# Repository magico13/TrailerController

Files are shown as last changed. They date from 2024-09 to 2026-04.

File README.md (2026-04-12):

# TrailerController

An open-source trailer controller emulating a Tesla trailer control module.

The goal of this project is to openly document how to create a controller that plugs into the gray 3-pin connector included on Tesla vehicles, to be able to control a 4-pin US trailer connector without needing to interface with any of the vehicle's other wiring.

The vehicle used for testing is a US-spec, Fremont factory, 2022 Tesla Model 3 LR AWD built November 2021, which puts it as SOP5. The vehicle is a HW3, MCU2 (Intel Atom), with a standard 12V lead-acid battery and ultrasonic sensors. Vehicles built starting around December 2021 shipped with a higher voltage lithium ion low-voltage battery (around 15V) and MCU3 (AMD Ryzen) with no ultrasonic sensors, and while this project should hopefully work for them the higher voltage may require some component changes.

At the time of writing, this project is intended to be passive, only reading information from the vehicle computers without attempting to send any commands to the vehicle. This is safer from both a security perspective and from the perspective of potentially damaging the vehicle electronics.

## OEM Tesla Parts

Note that since the Highland Model 3 now has an official tow package, a US-spec official ECU is available straight from Tesla that is plug and play with the older Model 3s as well. As of writing (April 2026), you can buy the ECU and the 4-pin connector from Tesla for about $100.

ECU: `1112581-00-A`
Harness: `1446560-00-A`

If you want to build your own for some reason, for example you don't want the car to disable anything when you attach a trailer, then this repository may still have value for you. If you just want your trailer lights to work with an aftermarket hitch, just buy those parts from Tesla directly.

Update: Either I got a bad wiring harness or there's something different with the communication between my older car and the newer ones that those parts are for, because my lighting appears to be out of order. Headlights control one of the turn signals, one turn signal signals the other, and the other turn signal control the tail lights. It seems like I can either swap the wires around myself, or make an adapter that plugs in and remaps them. Be warned that using those parts might result in the same issue for you!

## Working Prototype

There is a working prototype with design files available in the [prototype.md](/docs/prototype.md) doc. Code for the prototype is available in the `/src/phase1` folder.

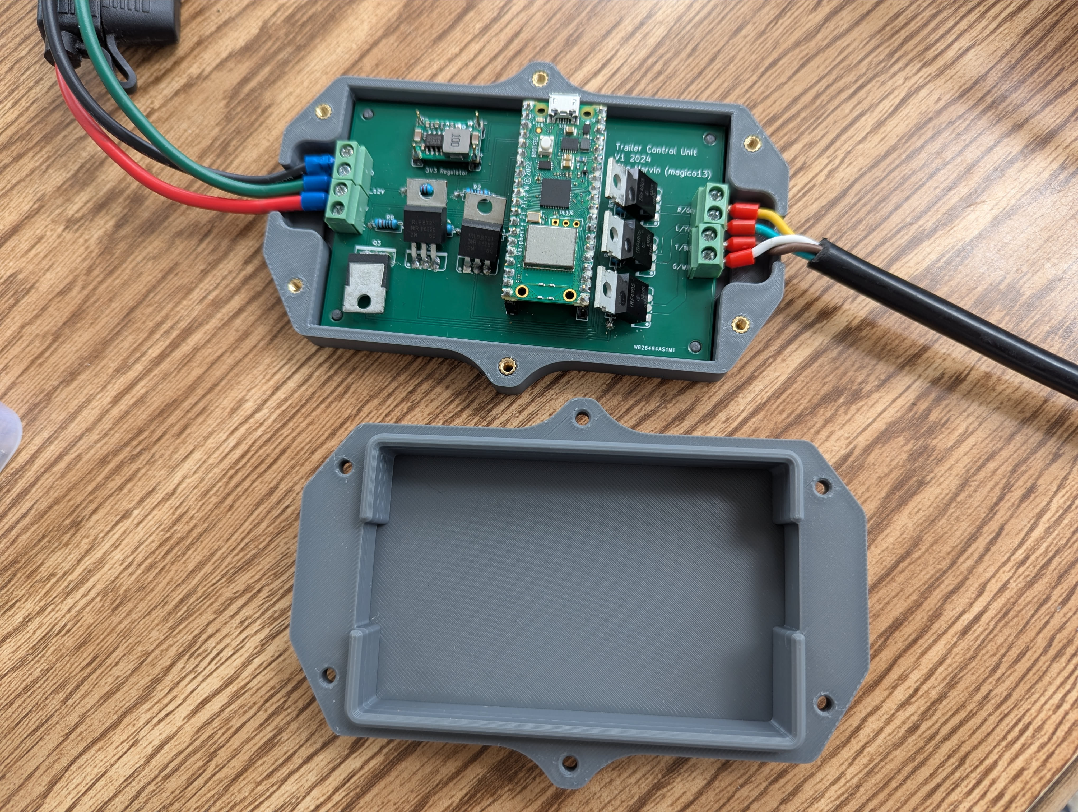
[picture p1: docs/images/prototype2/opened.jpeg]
Prototype Image


## Motivation

Currently it is difficult or impossible to find documentation of how to interface with the Tesla trailer wiring to get a standard 4-pin connector. In Europe, the "gray connector" (as it's often referred to online, see [teslamotorsclub forum](https://teslamotorsclub.com/tmc/threads/model-3-tow-hitch-installation-ecohitch-and-near-factory-wiring.323758/)) connects to the Trailer Control Unit which interprets the signals from the vehicle's computer and adapts to the standard [European 13 pin connector](https://en.wikipedia.org/wiki/ISO_standards_for_trailer_connectors#13-pin_trailer_connector_(ISO_11446)). In the US the controller is missing but the wiring up to it is present (as of 2019), terminating in the gray connector with id `X041` in the Tesla service manual.

~~I have seen reports that you can use the OEM trailer control module for a Tesla Model Y with the Model 3, to get the US 7-pin connector, part number `1764896-98-D`. Used on ebay they look to run about $300 USD but provide an OEM route for this functionality.~~ (See above, there is an official US Model 3 part for this now.) This alone does not enable the trailer mode in the software, but there are ways to do that with the Tesla Toolbox software.

There is an existing third-party module available online which goes by the part number `TM3-TDW06-US` which does precisely what this project aims to do. I cannot speak to the quality of the product, but it retails for about $400 USD and as far as I can tell the hardware and software are not open-source.

Instead of reusing this conveniently placed connector, most people opt for using "dumb" wiring harnesses that monitor the wires for the tail lights and turn signals and run a wire to a 12v source (sometimes all the way up to the battery in the front of the car) for power. Some of these wiring harnesses require electrically connecting to the wires by clamping onto and piercing the insulation of the wires, such as the "passive" wiring harness provided with the Stealth Hitch. Others monitor the wires using inductive sensors that wrap around the wire but do not pierce the insulation, but still require finding appropriate wires to intercept.

I have seen reports of people doing exactly what this project aims to do, ie listen to the communication from the vehicle over that connector and actuate the appropriate lights on the trailer, but have yet to see anyone document the process in a way that can be used by the community. Even if the wiring is relatively simple, decoding the communication is an annoying process to repeat for everyone who wants to create their own controller. I hope this project will eliminate the amount of rework required and provide a suitable starting point for anyone looking to create their own controller.

## General Plan

I expect there to be at least 3 phases of this project.

### Phase 0 - Decoding and Documenting

Documenting information about the connector on the vehicle and developing a controller that can listen to communications from the vehicle, so that we can also decode them and establish which messages indicate that the turn signals, brake lights, and headlights/taillights are active.

### Phase 1 - Functional Prototype

Taking the info from Phase 0 and building the first prototype trailer controller that will properly actuate the trailer lights via a 4-pin connector. This might be as basic as a bread-board or perf-board and not water-resistant, just a proof of concept of everything working together. This is sufficient for the purposes of this project, in that it provides all of the information required to build a custom trailer controller including functional software and hardware examples. It does not, however, get me personally to a state where I can use a trailer with my car for very long or in inclement weather.

### Phase 2 - Permanent Controller

Enhancing the prototype into something that can be installed permanently in the vehicle is a bit of a stretch goal for the project, but something that I want to personally achieve for my vehicle. This may involve custom PCBs and enclosures and additions to the hardware that are not required for a minimally viable product, eg temperature sensors and detecting if a trailer is connected. At this point I may also investigate sending data back to the vehicle to let it know if a trailer is connected, so that trailer mode could be engaged if enabled in the software (the controller cannot enable tow mode itself, the main software must be updated through Toolbox to allow it). While all the hardware and software produced at this stage will remain open-source, I may opt to sell completed or kit versions of the final result if there is interest.

## Docs

Check the docs folder for the most up-to-date information about the connector, communication, and the latest project status. These documents will be living documents during the research and development of this project.

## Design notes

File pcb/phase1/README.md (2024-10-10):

# phase1

## Description

Schematic and PCB for phase 1. PCB is definitely optional, but may provide a starting point. At the very least, it's good learning for me to make.

This is a [LibrePCB](https://librepcb.org) project. LibrePCB is free, open-source, and cross-platform.

## License

See [LICENSE file](../../LICENSE)

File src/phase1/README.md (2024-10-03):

# Phase 1

This second phase is for building a prototype controller. While an ESP32 was used for the first Phase 0, a Pi Pico W is being used here. Some of the fancier OTA support is lost as a result.

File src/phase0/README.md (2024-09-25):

# Phase 0

This first phase is just to get a device connected to the LIN network and listening to the communication so we can find the messages we need to trigger off of. This folder specifically contains the source code for the ESP32 doing the listening.

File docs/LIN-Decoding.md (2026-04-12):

# LIN Decoding

The communications from the vehicle to the trailer control unit are performed over the thinner middle wire in the connector (see [X041.md](./X041.md)) which communicate via a [Local Interconnect Network](https://en.wikipedia.org/wiki/Local_Interconnect_Network), ie LIN. Notably, LIN is not CAN (Controller Area Network), but instead is a cheaper and simpler serial communication protocol that is bidirectional via a single communication wire.

During Phase 0 of the project this page will (hopefully) document the communication happening via the LIN wire and identify the message(s) that provide the information we need to run the trailer lights.

## Target information

This is the information that we definitely will need to read from the LIN to activate the correct lights.

- Brake light status
- Left/Right turn signal status
  - Will the messages indicate the current state of the light within the cycle (on/off) or instead just that left/right is requested?
  - Are hazard lights communicated differently?
- Taillight/Headlight status
  - Specifically the taillights are what is required, but that may only be communicated by if the headlights are active
  - If headlights only, regular vs brights may be communicated differently?

## Hardware Setup

To connect to the vehicle and read the data I am planning on using an ESP32 with one of the serial RX pins connected to the LIN wire. Since the LIN uses 12V and the ESP32 is 3V3 and we only need to read data, a simple voltage divider to cut the voltage to about 1/5 of normal should suffice to prevent the ESP32 from being overvolted. I plan on powering the ESP32 directly from the 12V wire via the VIN pin and use the onboard regulator, but in the future a separate (probably switching) regulator to drop to 3V3 that can definitely handle up to about 20V should be used instead.

I am opting for an ESP32 because WiFi capability means I can update the firmware and get data without having to run a wire to the controller from my computer (meaning I can hopefully sit in the drivers seat and read data as I activate things) and because there are [existing LIN libraries](https://github.com/iDoka/awesome-linbus) for the ESP32. I may instead swap to a Raspberry Pi Pico W in the future, or to a custom RP2040/RP2350 board. Using a standard and relatively inexpensive development board means that everything is easily replicated by anyone else wanting to create a custom controller using this information.

The source code provided in this project is set up to use PlatformIO via Visual Studio Code, which should make it relatively simple to update and flash on your own hardware.

The circuit diagram for the reader is below, basically just a voltage divider using 47kOhm and 10kOhm resistors to drop the voltage to below 3.3V and into a safe range for the RX2 pin on the ESP32. I ended up logging to serial rather than building out a web server, so power was generally provided by USB rather than the 12V.

Circuit diagram

Alternatively, use a dedicated USB signal analyzer, which is what I ended up doing later, using the PulseView software for Linux. For reference, 100kHz sampling rate seemed to work fine, which is about 5x the data rate.

## LIN Information

There are some basic settings for the LIN bus that seems to be common between at least the LIN bus for the trailer and the inductive charger:

- LIN checksum version: 2
- Baudrate: 19,200 bits/s
- Data length: variable

Example trace from the inductive charger LIN bus:
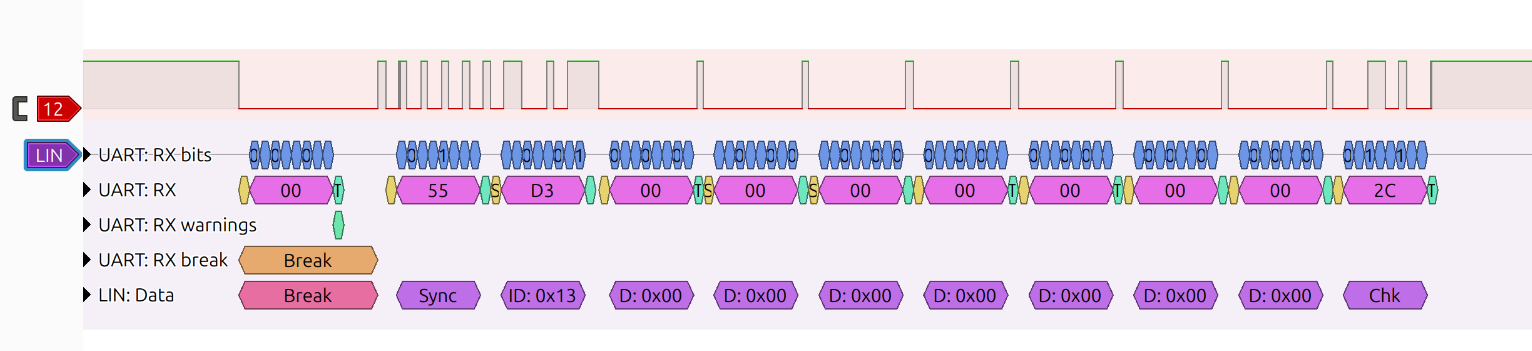
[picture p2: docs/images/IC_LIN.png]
IC_LIN example


~~Further testing indicates that the same data looks to be sent over both LIN buses. The light info for the trailer can be read over the LIN for the inductive charger, which makes debugging much easier since that can be read from within the cabin.~~

While the above is true, newer documentation for the Highland Model 3 shows that LIN bus 2 from the left body controller contains both the trailer LIN and the inductive charger LIN on the same bus. There are additional LIN buses in the vehicle, but those two will always both be available together, which is extremely convenient because that means we can access both from either the rear bumper, or from the center console.

## Testing Setup

Within the center console, the connector numbered `X930` within the Tesla documentation is the one we'll be interfacing with for reading data and testing purposes. One option for probing here is to insert male jumper cables for breadboards into the backs of the connector, which is what I did for a long time. However, there are a plethora of aftermarket OBD2 adapter harnesses you can buy that are installed in-line with this connector, which you can modify without worrying about damaging the original wires or having to build a whole pass-through harness for the three wires we care about. I ultimately ended up modifying the one I already had installed for Scan My Tesla and added the same female connector that exists in the rear bumper for the trailer ECU.

On my vehicle, pin 1 on this connector is 12V, pin 6 is the LIN bus, and pin 26 is ground. Double check via Tesla's documentation for your specific build, and also with a multimeter! Searching for `X930` in the interactive schematics on Tesla's service website should be enough to pull up the pinout.

The picture below shows the testing setup with a full prototype unit, but the same basic idea works for testing with just a signal analyzer.

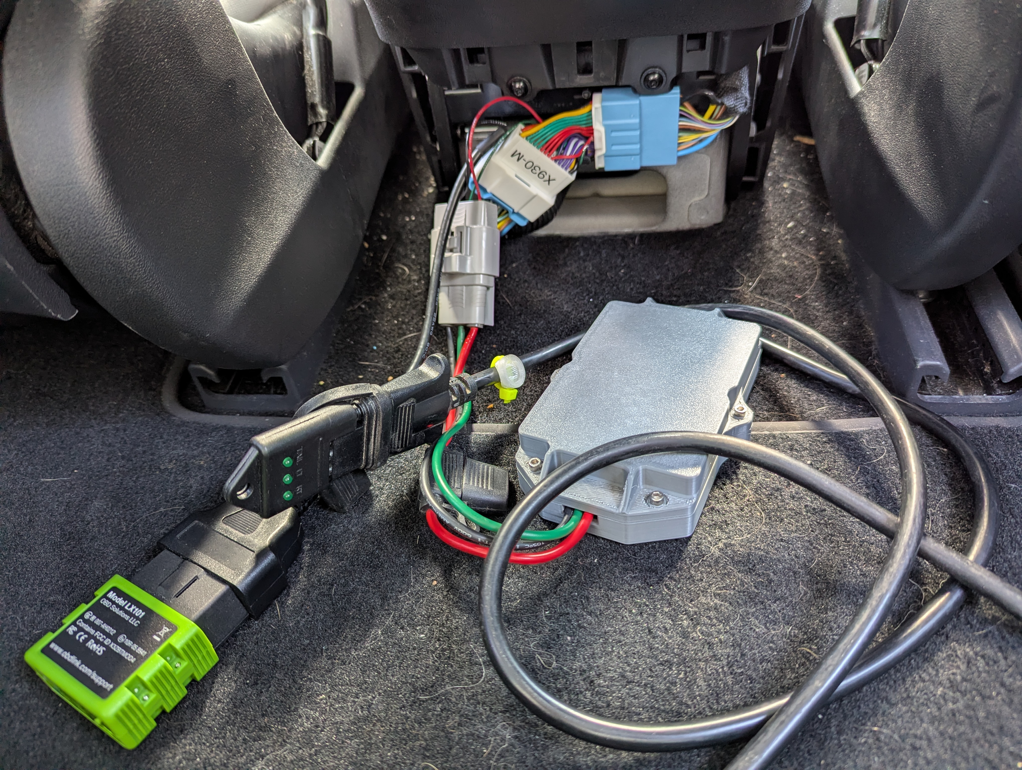
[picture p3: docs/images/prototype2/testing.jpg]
Setup


### Reading the Lights Data

As you can tell if you look at the raw data below, the key message for the data on which lights are lit is the message with ID `0x0F`. This message has a single byte of data containing flags for the relevant lights.

In least significant bit first ordering (how the data is sent over UART):

- Bit 1: Left turn signal
- Bit 2: Right turn signal
- Bit 3: Headlights
- Bit 4: Brakes
- Bit 5: Unknown
- Bit 6: Reverse lights
- Bits 7-8: Unknown

Both of the turn signals are also marked as active when the brakes are pressed, so that doesn't need to be handled separately.

This means that mapping the message to the lights on a four-pin connector is just:

- left/yellow maps to the first bit
- right/green maps to the second bit
- taillights/brown maps to the third bit

#### Examples

- Driving with the headlights on: `00100000` = 0x08
- Headlights on, turning left: `10100000` = 0x09
- Slowing down with brakes, headlights off: `11010000` = 0x0A

### LIN Frames

This is a raw list of the different ids and sample data seen for the Trailer LIN bus. Number are hex unless otherwise specified. ID is the actual identifier, PID is the raw Protected Identifier Field including parity bits.

#### 0x0F - Light States

- ID: 0x0F
- PID: 0xCF

IDLE

- Data: 1 byte
  - 0x00
- Checksum: 0x30

LEFT TURN

- 0x01
- Checksum: 0x2F

RIGHT TURN

- 0x02
- Checksum: 0x2E

LIGHTS ON

- 0x04
- Checksum: 0x2C

BRAKES

- 0x0B
- Checksum: 0x25

DRIVE - HOLD ACTIVE

- 0x0F
- Checksum: 0x21

REVERSE - HOLD

- 0x2F

REVERSE - MOVING

- 0x24

#### 0x10 - Data from ECU to Car

- ID: 0x10
- PID: 0x50
- Without ECU: No data, expecting response
- With ECU:
  - Park, no connection: 5 bytes
    - 0x00
    - 0x00
    - 0x2C = `00101100`
    - 0x01
    - 0x00
    - Checksum: 0x82
  - Park, connected: 5 bytes
    - 0x49 = `10010010` determined to be left test/status/unknown, right test/status/unknown, tail test/status.
    - 0x00
    - 0x2C = `00101100`
    - 0x01
    - 0x00
    - Checksum: 0x39
  - Park, only tail lights (car thinks left turn):
    - 0x81 = `10000001`
    - others unchanged
  - Park, only LT (car thinks right turn):
    - 0x08 = `0010000`
    - 0x00
    - 0x30 = `00001100` <- different!
    - 0x01
    - 0x00
    - Weirdly, the car indicates the left is out and the right is fine (fast left blinks, normal rights)
  - Park, only RT (car thinks tail lights):
    - 0x40 = `00000010`
    - 0x00
    - 0x30 = `00001100`
    - 0x01
    - 0x00
    - Car indicates both left and right are in error.

  Uh oh, testing with my light tester shows that either the harness is wired wrong or there's a bug in the ECU code because the RT light is tied to the headlights, LT light is tied to RT, and Tail lights is tied to LT. That's a huge issue for using the existing ECU, I will need to investigate further.

  - Reverse, fully connected, brakes active
    - 0x5B = `11011010` - left good, left active, right good, right active, tail good, tail off
    - 0x04 = `00100000`
    - 0x51 = `10001010` - first bit seems to be "reverse" but otherwise I don't see a consistent pattern
    - 0x01 = `10000000`
    - 0x00

  - Drive, connected, free rolling:
    - 0x49 = `10010010`
    - 0x00
    - 0x50 = `00001010`
    - 0x01
    - 0x00

  - Drive, connected, headlights on, free rolling:
    - 0xC9 = `10010011` - left/right good, tail good, tail active
    - 0x00
    - 0x50 = `00001010`
    - 0x01
    - 0x00
  
  - Drive, connected, brakes on:
    - 0x5B = `11011010`
    - 0x04 = `00100000` definitely seems brakes related
    - 0x50 = `00001010`
    - 0x01
    - 0x00

#### 0x11 - Unsure, comes from trailer ECU

- ID: 0x11
- PID: 0x11
- Without ECU: No data, expecting response
- With ECU:
  - Park, connected or not: 8 bytes
    - 0x01
    - 0x00
    - 0x00
    - 0x00
    - 0x00
    - 0x00
    - 0x00
    - 0x00
    - Checksum: 0xED
  - Drive, brakes active, right turn signal
    - 0x86 = `01100001`
    - 0x03 = `11000000`
    - rest 0x00
  - Drive, headlights on, rolling
    - 0x02 = `01000000`
    - 0x01 = `10000000`
    - rest 0x00
  - Drive, brakes (and also Reverse, brakes)
    - 0x86 = `01100001`
    - 0x85 = `10100001`
    - rest 0x00

#### 0x13

- ID: 0x13
- PID: 0xD3
- Data: 7 bytes
  - 0x00 (for all bytes)
- Checksum: 0x2C

#### 0x18

- ID: 0x18
- PID: 0xD8
- No data, expecting response

#### 0x19

- ID: 0x19
- PID: 0x99
- No data, expecting response

#### 0x29 - Driver Side Wireless Charger

- ID: 0x29
- PID: 0xE9
- Data: 8 bytes
  - 0x02
  - 0x00
  - 0x1C
  - 0xF3
  - 0x01
  - 0x88
  - 0xFF
  - 0xFF
- Checksum: 0x7A

Driver IC Charging

- The first byte changes from 2 to 3, to 8, 9, and then 0x0A when a device is placed on the driver's side charger, but not the passenger side.

0x01 is disabled?,
0x02 is idle,
0x03 is testing for a device,
0x08 and 0x09 seem to be preparing,
0x0A is actively charging.

The second byte seems to also be a state identifier: 0 for no device, 1 for present but not charging, 2 for charging.

#### 0x2A - Passenger Side Wireless Charger

- ID: 0x2A
- PID: 0x6A
- Data: 8 bytes
  - 0x02
  - 0x00
  - 0x00
  - 0x1C
  - 0xF3
  - 0x01
  - 0x88
  - 0xFE
- Checksum: 0xFA

#### 0x2C

Note: I only saw this for the first time after installing the ECU, but a lot of time passed between the first data I captured and then, so I do not know when this was added.

- ID: 0x2C
- PID: 0xEC
- Data: 8 bytes
  - 0x03
  - 0x00
  - 0x00
  - 0x00
  - 0x00
  - 0x00
  - 0x00
  - 0x00
- Checksum: 0x10

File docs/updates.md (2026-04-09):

# Updates

## 2024-09-25

First attempt at using some fairly simple code to sniff the traffic on the LIN bus for the inductive phone charger did not really go well. May have been as simple as a timing problem, may have been that the code I found wasn't built to handle a real LIN bus and was intended for a bus of your own devices. I have ordered an inexpensive USB logic analyzer and am hoping looking at the raw signals will help me understand how to either modify the code I am using or write a whole new library if necessary.

I have also ordered a TJA1020 transceiver module. I am hoping not to need it for just sniffing the traffic but it might make development easier and will basically be required if we ever want to send data back to the controller and pretend to be the real trailer module.

You may have noticed up there that I mentioned the inductive phone charger LIN and not the trailer LIN. The connector for the trailer LIN, [X041](./X041.md), is pretty firmly trapped in the bumper in a way that prevents any access until you take the bumper off. I will reposition it when I install my hitch since I'll be in there anyway and I'm likely going to need to connect to it often during testing. Until then, for the purposes of testing whether or not I can even read data from one of the LIN buses, the bus for the inductive phone charger is much easier to access.

For reference, it's on PIN 6 of connector X930F in my model 3. That connector is the one in the bottom rear of the center console, the same one that OBD adapters are usually made to connect to. Pin 7 is conveniently a ground pin. You can disconnect that plug, stick two male jumper wires in, and have access to the LIN bus while sitting comfortably in the back seat of the car. If/when I also need 12V it can also be pulled off that connector, for example pin 15 (big one in the bottom left) looks to be the 12V for the USB ports.

I will likely continue to use that LIN bus for testing until I can reliably read data from the bus, then move to the trailer bus.

## 2024-09-26

While I wait for the USB logic analyzer to arrive I realized that I could probably use the ESP32 itself as a logic analyzer. Using [this project](https://github.com/EUA/ESP32_LogicAnalyzer) with a tweak to the `platformio.ini` file to use `espressif32@4.1` to fix the compatibility with `esp32doit-devkit-v1`, I was able to successfully read the data from the inductive charger LIN bus, though with the sensors disconnected so there was no response data (ideally I will be able to intercept it while active). That was enough to confirm some details of that LIN bus that will hopefully translate over. I'll update the [LIN bus doc](./LIN-Decoding.md) with some of that info. Additionally the sigrok/PulseView file itself is in the phase0 docs folder, [here](/src/phase0/data/IC_LIN_Trace).

Assuming the setup is the same for the trailer LIN, we at least know the protocol version (2), baud rate (19200), and to expect the amount of data per response to change between 2, 4, and 8 bytes. I think that might be why the code I was using earlier failed since I believe it was assuming the response was always 8 bytes. If I can change that to pick the right number of response bytes, maybe it'll work.

## 2024-09-29

Installed my hitch yesterday and freed the connector for the trailer wiring so that I can easily connect/disconnect from it. Ideally anyone following this will not need to move it and can leave it in the relative safety of the upper part of the bumper on the support beam, but I need to be able to freely and temporarily connect things to it.

With that available I was able to get readings from the LIN bus with the turn signals, brakes, and lights on. Now I just have to analyze the different frames and see what's different in each scenario.

## 2024-10-02

For Phase 1, the prototype controller, I am swapping to a Pi Pico W from the ESP32. I want to experiment with different hardware a bit and there are aspects of the Pico and its production that I prefer. Sadly the nice OTA library I was using doesn't play as nice, though might be able to come back without the async functionality. Also realized the other day that the MOSFETs that I got are better for low-side switching and we need high-side switching, so I got some others I need to do testing with. Annoyingly it looks like I need to use both types to be able to switch it. I have some experience with building circuits and PCBs and such, but not quite the level that would make this project easy for me.

## 2024-10-06

Prototype PCB design is finished enough to send off to get the first samples. Fingers crossed I didn't mess anything up too badly, I'll know in about a week if the estimates are to be trusted. With only 1 oz copper the lighting traces might only be good for about 3 amps, I'll have to test one of the boards at high current and see how it behaves. Ideally for a final product I'd double the copper but that increased the cost significantly, not worth it for a prototype where I know I'm only going to drive LEDs and I don't know if the board is even gonna work. Here's hoping I'll have some assembly and testing news in my next update.

## 2024-11-04

Prototype boards arrived and I've built one up. Works more or less perfectly! I did tweak the silk screen a bit since then to hopefully make the labels for the terminals more clear when the terminal blocks are attached, right now they are mostly covered. Designed and printed a pretty basic enclosure but it's both too big and too small. The horizontal space inside is a little tight, you may want to make it a bit wider to give more room for the wires coming into the terminal blocks. But it's also pretty tall, which could be improved if you bent the MOSFETs instead of leaving them straight like I did. You could go even thinner if you directly mounted the Pico. As it stands I've got it tucked into the space between the back of the bumper and the battery, my cable from the car is pulled all the way down so I can easily plug it in or take it out. I do not know if the case as designed will fit inside the bumper on top of the aluminum support where the connector from the car is normally located. I'll post pics and some more info in [prototype.md](/docs/prototype.md)

## 2026-04-05

Between the last update and now I had kept the prototype in my car for several months, over the winter even, and had used it to tow a Home Depot 5'x8' trailer once without issue. I took it out to see how it was doing, especially because I hadn't sealed the holes in the enclosure and where it sat on the underbody tray would often end up with puddles of water. Several of the exterior screws I used had rusted but the PCB itself looked fine, however once screw got stuck to the brass insert and I ended up ripping it out of the enclosure so I needed to print a new one. I figured since I needed to print a new enclosure anyway, it'd be a good time to redesign it to be smaller in the hope of fitting it higher up in the bumper and away from standing water. I'll put a few pictures of the new design up.

I've periodically been making small updates to the firmware. I'm trying to rewrite the LIN decoder because although it works perfectly fine for the short message used for the lights control, it struggles with longer messages and keeping up with the full unfiltered message list. I'd like to add a built-in data logger for monitoring the LIN bus in case anything changes or I want to try to monitor any of the other messages on the bus, although this particular one should only be the trailer hitch ECU and the wireless charger ECU.

Also since then, the Highland Model 3 in the US has gotten an official tow hitch, and the Highland appears to use the exact same wiring setup, meaning the ECU for that model should work just fine in earlier model years. You can find that ECU on the Tesla parts catalog under `1112581-00-A` and per their website it's only $60, though on eBay it's over $100. I have ordered one to try it out, if that works without issue then it would definitely be the recommended way to handle the trailer lights even with an aftermarket hitch. If you go this way, make sure to also order `1446560-00-A` which is the wiring from the ECU to the 4-pin connector, which is an additional $30.

And finally, I will provide some documentation around the LIN bus that you can access in the center console. I noticed I hadn't documented that thoroughly, including writing down the connector number (it's `X930`) anywhere for looking up the pinout, which caused me a lot of wasted time trying to find that again when I wanted to set up a more permanent test setup in my car with the same connector as what's in the bumper area.

## 2026-04-08

Good news! The parts listed above from Tesla seem to work perfectly! Even without the towing software installed (which is technically already installed but not enabled, you supposedly can enable it with Toolbox but that's like $75 minimum just to rent the software for a day), when plugging in a trailer (or just a tester in this case) the car will display a yellow trailer icon on the screen. It will also show red if one of the lights doesn't appear to be working, though doesn't seem to tell you which of them is faulty. Based on the lights on my tester, the ECU just sends a pulse every second to see if the lights are working and a trailer is attached. I am not sure if that only happens in park or even in drive and I haven't had a chance to sniff the LIN bus to see what data the ECU is sending back to the main controller.

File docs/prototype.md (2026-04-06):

# Prototype 1

This is the result of Phase 1, a fully functional but fairly basic initial prototype. This can be used as-is, though if you're going to make it I recommend some tweaks that you can look into implementing yourself.

## Final Result First

Here's the final result first, if you want to read more about the PCB and the components you can keep scrolling down.

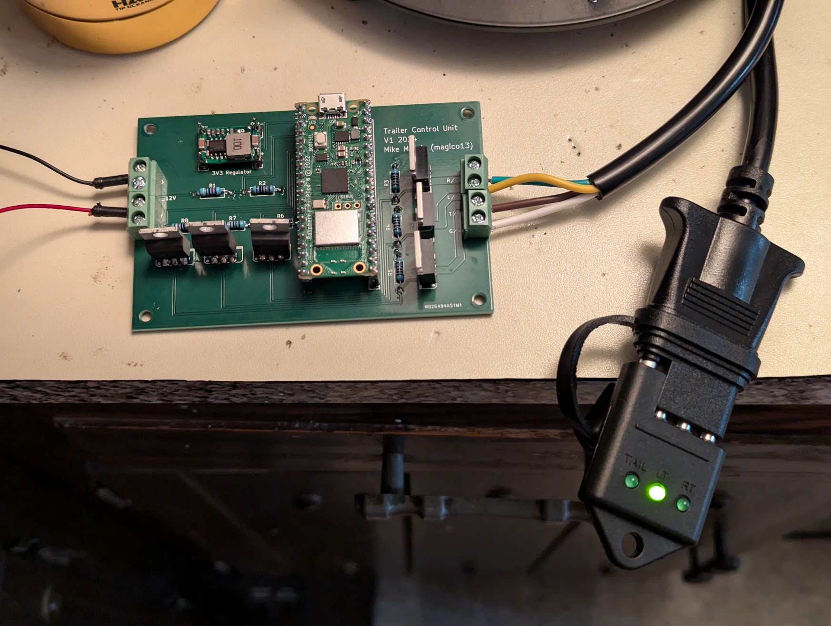
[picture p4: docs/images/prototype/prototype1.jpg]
Prototype Picture

EnclosureOpen
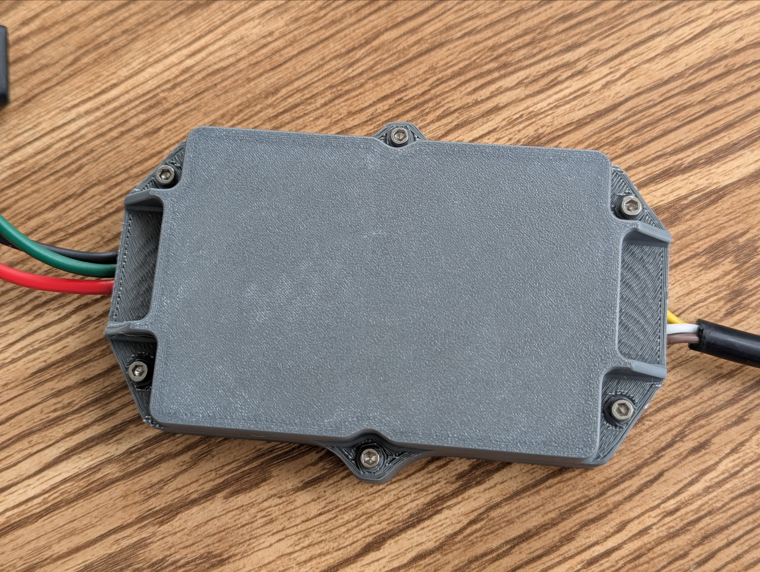
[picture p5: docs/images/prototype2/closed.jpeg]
EnclosureClosed

TestInstall

(the wiring is wrong in the picture of the open enclosure, the yellow and green are swapped, I fixed that later)

## PCB Design

The PCB was designed with LibrePCB, which is free and cross-platform. The files for it can be found in the pcb/phase1 folder and LibrePCB will interface directly with PCBWay (who I used) and other fabs to get boards uploaded and manufactured without having to do any exporting of files or much in the way of configuration. I did opt to put `WayWayWay` at the bottom of the board to force the PCBWay serial into that location, make sure to check that option if you use PCBWay or remove that text if you don't care.

I am not very experienced with PCB design so there are definitely improvements that can be made. I wanted to provide what I created and used as a stepping stone for anyone else who might want to do something similar. If you are more experienced or think you can make something better, please do and share it!

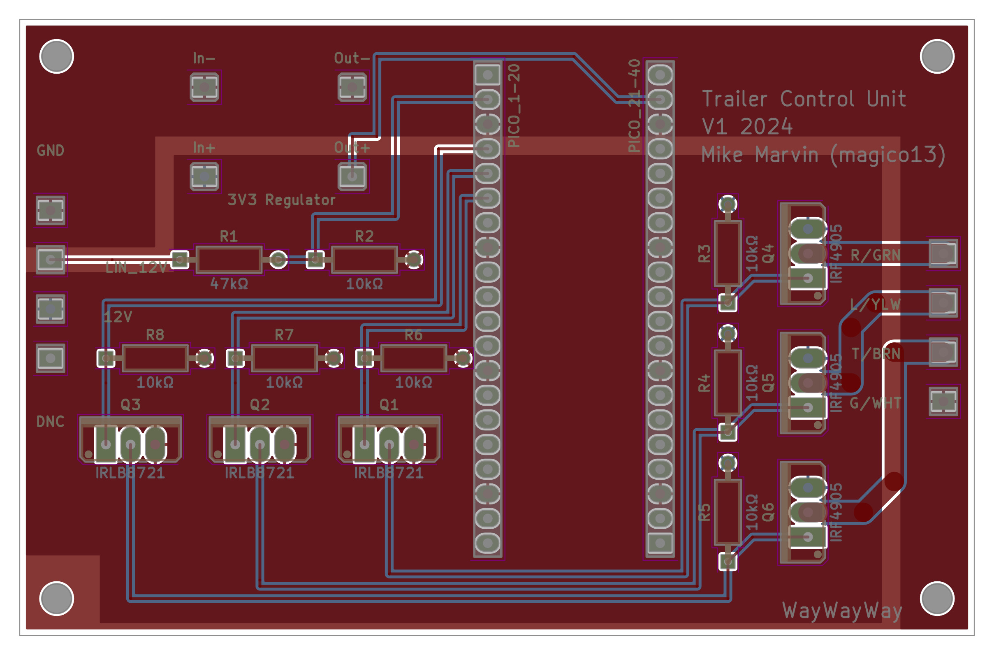
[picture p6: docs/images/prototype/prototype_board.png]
Prototype Board

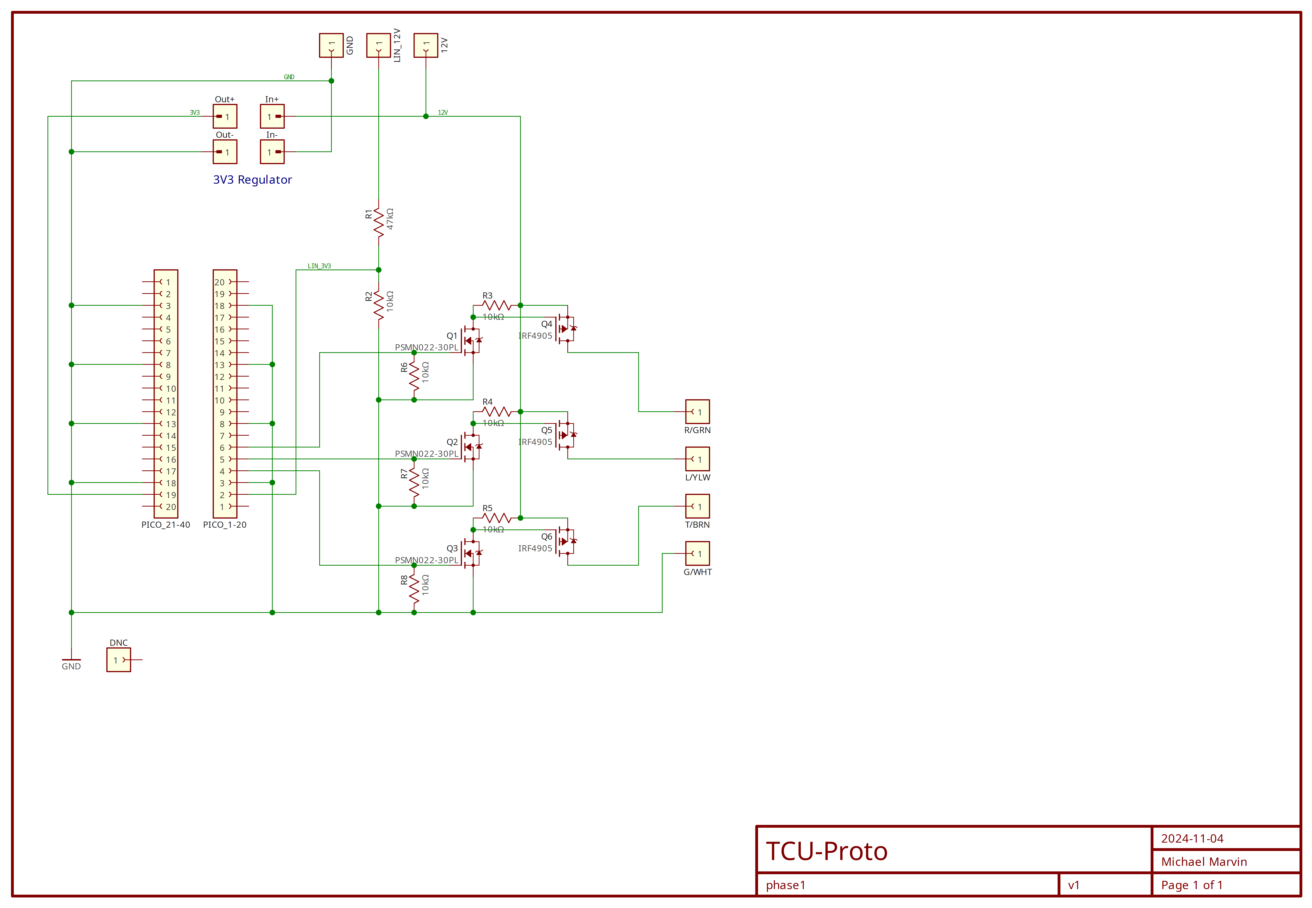
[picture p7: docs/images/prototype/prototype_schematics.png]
Prototype Schematics


## New Enclosure

See below for details about the old, larger enclosure, which is still available via OnShape. For the updated enclosure, the MOSFETS must be bent so they don't stick up past the Raspberry Pi Pico, but it shaves off a fairly good amount of height and is about the same width with the wings, it'd be noticeably smaller if you removed them from the model but I'm not sure if the outer four screws are enough or not. This update was also made in OnShape at the same link. This new enclosure doesn't use screws to hold down the PCB, instead the inner walls of the top of the enclosure hold it down and there are pins that the mounting holes on the PCB sit on, so that removes four screws and brass fittings. The design does unfortunately require support and was designed around a 0.4mm nozzle, if I make more updates to it I will try to reduce the support requirements, but in this case I had to decide between really long screws or using support.

The new enclosure is designed so that the PCB can be removed without removing the wires from the terminal blocks, and so that the pico's USB port is accessible even while the PCB sits in the bottom of the enclosure. The intent is to fill the wire openings with hot glue or epoxy or something similar to seal them, though I am also considering making a printable TPU gasket.

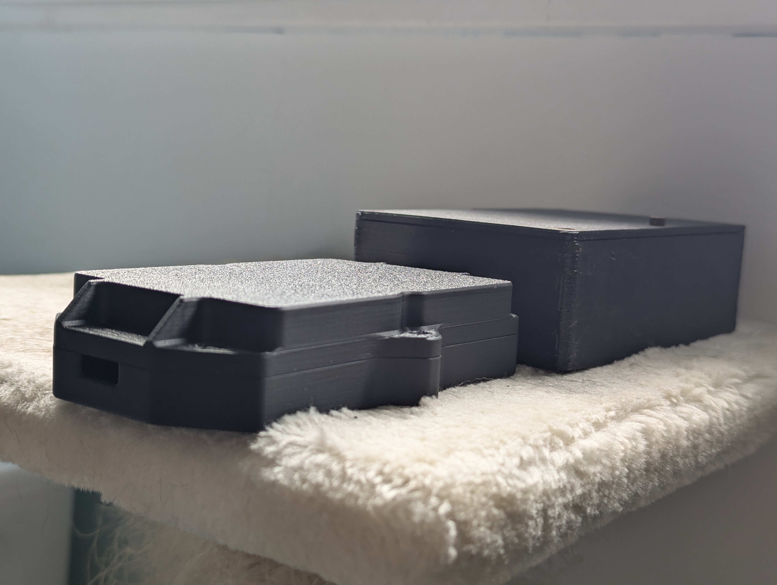
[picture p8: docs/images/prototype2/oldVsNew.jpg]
OldVsNew


The new one is black here because it was a test print in PLA, the final version was printed in a gray PETG.

## Old Enclosure

The enclosure was designed in OnShape. I tried to learn FreeCAD and it was too frustrating for me coming from Fusion 360, but I wanted something that worked on Linux. With OnShape being browser based it worked fine in Ubuntu or on my Windows desktop. With the public link you should be able to copy it to your own account to modify, or export it in whatever format you want. Again, I'm experienced enough to make something **functional** but not necessarily something **good**. I am not sure how this will hold up over time, or how water resistant it is. I printed it with a 0.6mm nozzle at 0.4mm layer height, but it was designed to also support 0.4mm nozzles for the walls. There's a rough model of the PCB with the terminal blocks, Pico, and MOSFETs included to help with positioning.

<https://cad.onshape.com/documents/38c75cc318c0ba98099f4117/w/3ef348a47c70d4d10d24442a/e/2bfd670c77f872a4c310e10b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>

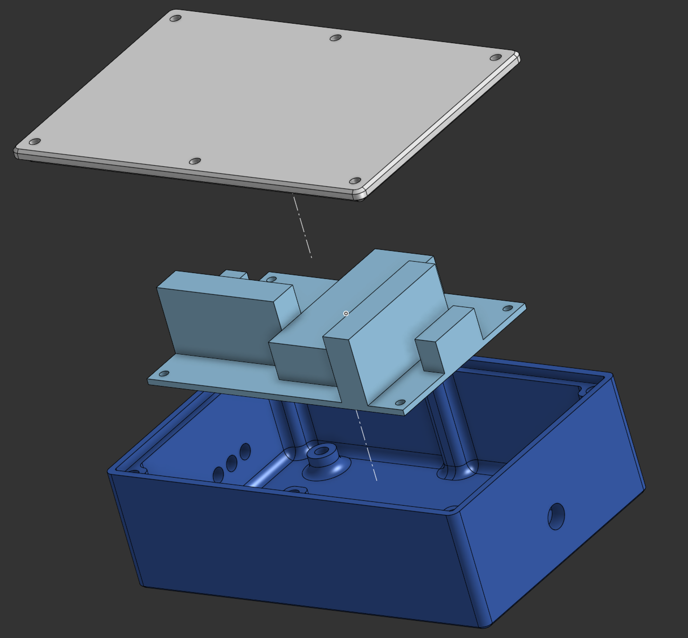
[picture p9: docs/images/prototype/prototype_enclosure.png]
Enclosure


## Bill of Materials

If you want to build your own copy of one of these boards, here are the materials I used.

### Main PCB

| Name | Quantity | Link | Notes |
| --- | --- | --- | --- |
| Pi Pico W | 1 | [Raspberry Pi Official Site](https://www.raspberrypi.com/products/raspberry-pi-pico/?variant=raspberry-pi-pico-w) | You can use the non-wifi Pico if you want more security, but lose out on easy updates and control. |
| 1x20 female pin headers | 2 | generic | For the Pi Pico. You could optionally solder it directly. I had a 1x40 already that I cut in half. |
| IRLB8721 N-Channel MOSFET TO-220 package | 3 | <https://www.amazon.com/dp/B07LG5BCDY> | These are overkill for this application, you really just need something that operates at 3V3 gate voltage. They will not carry any real current. |
| IRF4905 P-Channel MOSFET TO-220 package  | 3 | <https://www.amazon.com/dp/B0CBKH44K5> | There are probably better choices but I had bought the N-Channels first before I realized you can't high-side switch with them and these are what I could get quickly. |
| 3V3 Regulator | 1 | <https://www.amazon.com/dp/B0B779CGJQ> | You could use a linear regulator instead for simplicity but that adds more heat. These have crappy spacing, 0.3625"x0.6". I used single male pin headers to affix them to the main board. If you plan to plug in USB to the pico while it's onboard, I recommend adding a diode because this doesn't like being run backwards. |
| 47kΩ resistor | 1 | generic | Only non-10kΩ resistor, used to drop the LIN Bus voltage to something the Pico can work with. This is R1 on the board. |
| 10kΩ resistor | 7 | generic | Used in the voltage divider for the LIN Bus and as pull-down/pull-up resistors on the MOSFETs. |
| 4x5mm/0.2" terminal blocks | 2 | generic, maybe <https://www.amazon.com/dp/B0D1GMMTZ5> | I already owned ones that were 2x so I used two next to each other. You can use a 3x on the car side, the fourth hole doesn't do anything but provide the option of using a 4x or two 2x terminals. |

### Enclosure/Other

| Name | Quantity | Link | Notes |
| --- | --- | --- | --- |
| M3 Heat-Set Inserts | 6 | <https://www.amazon.com/dp/B0CS6VZYL8> | 6 for the lid |
| M3x10mm bolts | 6 | generic | Longer will also work |
| Trailer Wire Harness | 1 | <https://www.amazon.com/dp/B0CM3Q5XL8> | The hole in the side is designed to fit the shielding of this pretty tightly. Others may work just as well. |
| Trailer Wire Tester | 1 | <https://www.amazon.com/dp/B07RT9CN3W> | Purely optional, nice for bench testing or if you don't have a trailer to test with. |
| Sumitomo 6188-0129 connector (with wire seals and blades) | 1 | <https://www.corsa-technic.com/item.php?item_id=1846> | See [X041.md](/docs/X041.md) for more details. |
| 12 gauge wire | 3 | generic | I had 12 gauge on-hand in red/black/green so that's what I used and what the holes are sized for. |
| Wire ferrules | 3 or 7 | <https://www.amazon.com/gp/product/B07WRQN45C> | These are generally recommended when you're using terminal blocks and stranded wire, but not strictly required. |
| 10-amp In-line Automotive Fuse | 1 | <https://www.amazon.com/gp/product/B01E5MM63C> | I've had this set for a while. A fuse is not strictly required but highly recommended. Might be tricky to replace if you tuck the TCU on top of the aluminum support. |

## Potential Improvements

In no particular order:

- Add a diode between the output of the 3V3 regulator and Pico to prevent backfeed when USB plugged in.
- Add smoothing capacitors across power lines.
- Shorten the height of the enclosure (further) by bending the MOSFETs (or SMD components).
- Better MOSFET choice(s).
- Resettable fuse if device placed out of reach (ie on the support beam).
- Automatically detect trailer connection instead of having to enable via web page.
- New PCB with surface mount components and much smaller size (ie Phase 2).
  - Potentially fully custom RP2040 setup, but would increase the complexity significantly.
- Different regulator. Either a basic linear one or otherwise put the power components on the PCB.
- Use TJA1020 or similar to send data back to the car.

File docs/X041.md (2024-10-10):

# X041 - The Gray Connector

X041 is the identifier of the "gray connector" for the trailer wiring harness in the Tesla service manual. The part is Tesla Part Number `1450449-00-A` and connector part number `Sumitomo 6189-0165`. The mating part that you would need to source to seamlessly connect to the connector in the vehicle is `Sumitomo 6188-0129` which can be found online via a variety of retailers, including AliExpress. I personally purchased mine from [CorsaTechnic](https://www.corsa-technic.com/item.php?item_id=1846) for about $5 plus $5 shipping, since shipping was from the US. I chose pins and seals fitting 3.00 mm<sup>2</sup> wire, as that is what is used for the power/ground wires on the Tesla connector.

The Tesla side of the connector has three wires, on the outside are red 12V and black ground in 12 gauge (TODO: confirm size) wire with the middle 18(?) gauge green wire being a Local Interconnect Network interface (see [LIN Decoding](./LIN-Decoding.md)) used for communicating vehicle status.

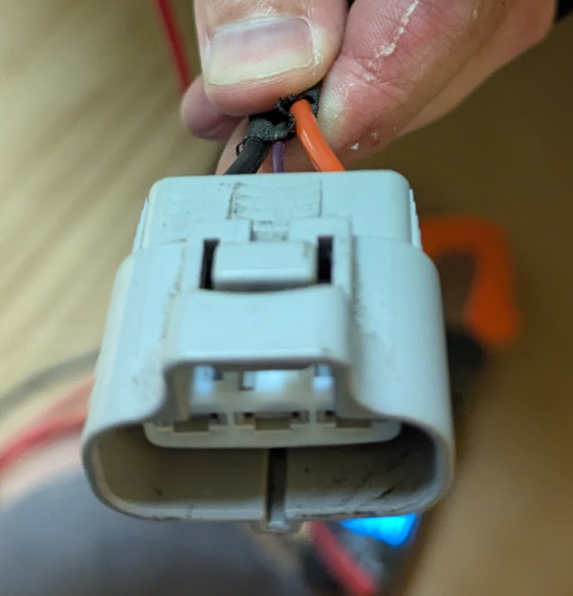
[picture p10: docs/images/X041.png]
X041 connector


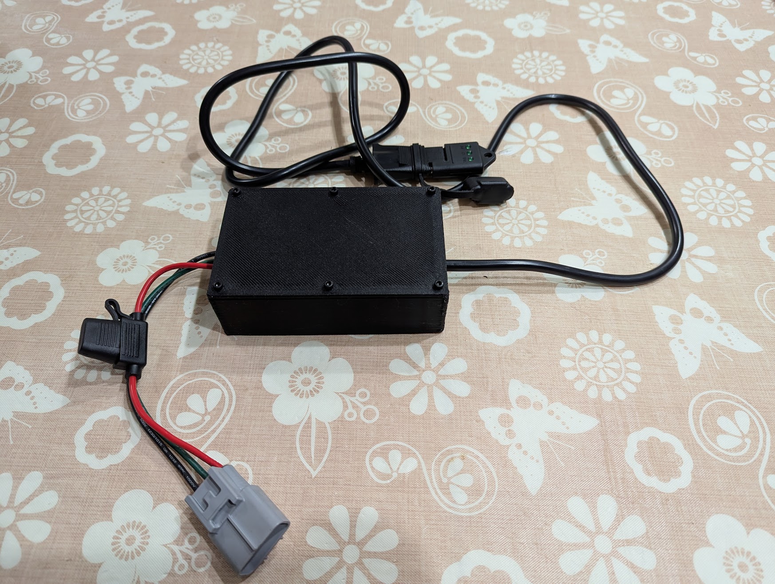
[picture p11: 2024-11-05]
docs/images/prototype/prototype4.jpg

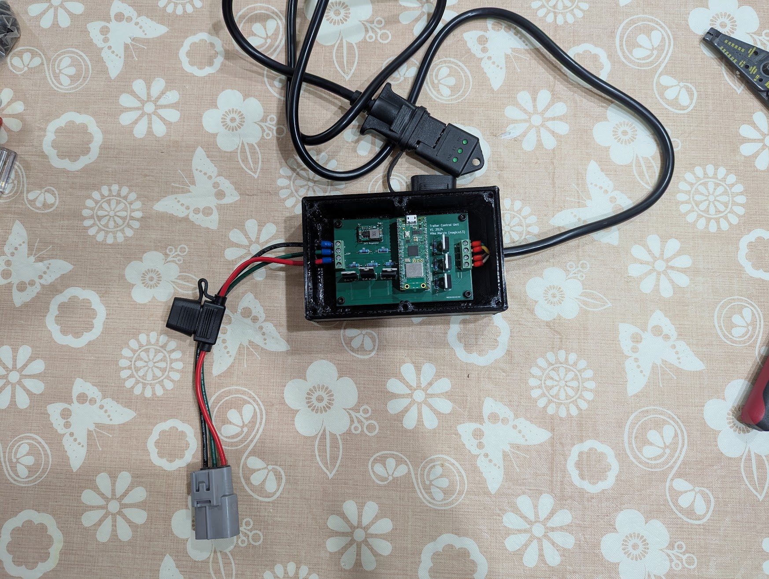
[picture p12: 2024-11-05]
docs/images/prototype/prototype2.jpg

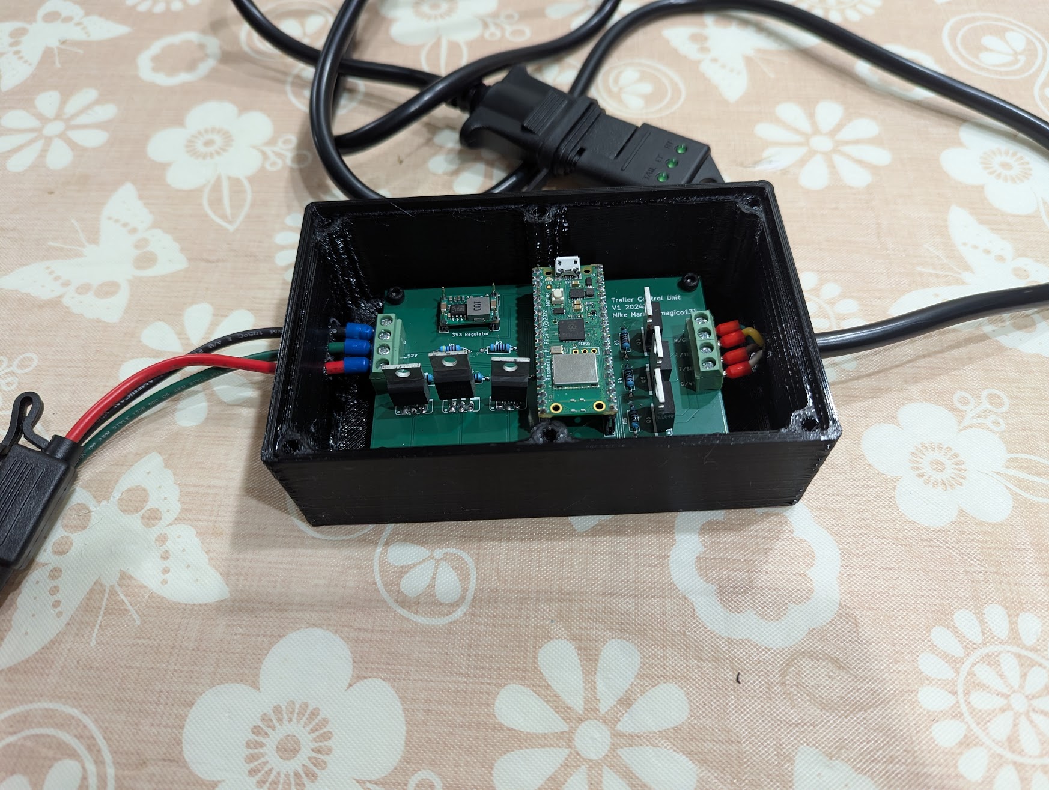
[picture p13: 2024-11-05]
docs/images/prototype/prototype3.jpg

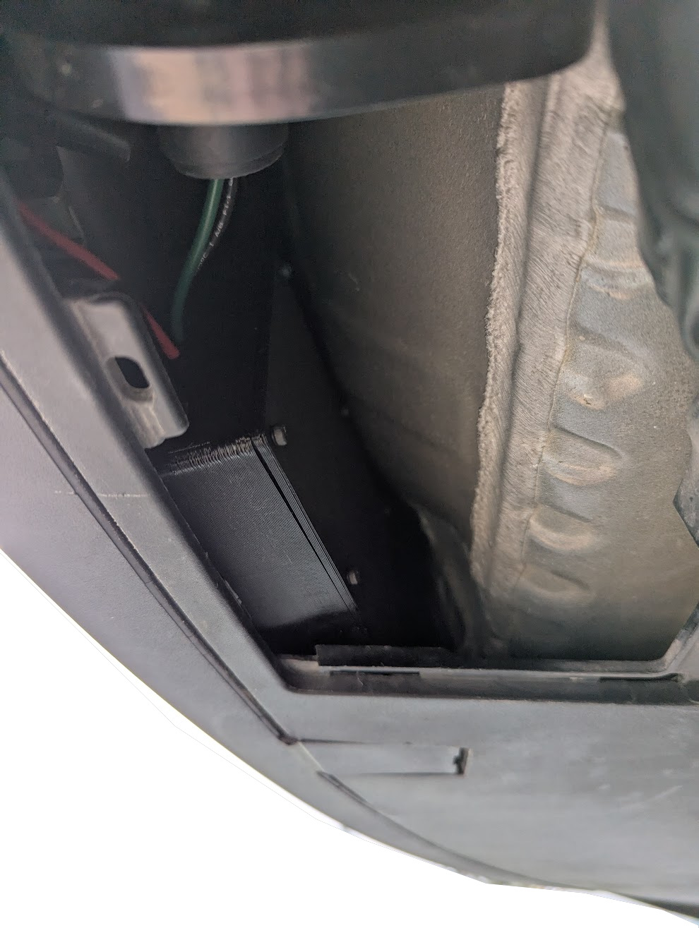
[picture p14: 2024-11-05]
docs/images/prototype/prototype5.jpg

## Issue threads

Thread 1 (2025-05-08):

nice work !

fiveangle, 2025-05-08:
I'd expect the backup light activation would be present in the stream as well, so if i get bored from the gazillizon other projects i've got, i'll look into it. I'm running the "dumb" Stealth box (lifting power from out the penthouse DC-DC conv. because when I saw their instructions to run a wire all the way to the batt, I just had to SMH).  But I recently got a trailer with a flat-5 trailer conn that implements bright backup lights that I'd really like to get working at some point, since the bu lights on my '18 P3 are anemic to say the least. I guess first I need to dig into iPhotos to see if any of the pics I took when I installed my hitch show that connector since it might not even be there.

Thank you so much for so thoroughly documenting your work here for all posterity ! ❤

Closed 2025-05-08.

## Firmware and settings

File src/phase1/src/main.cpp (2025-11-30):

/*
 * Pico W-based Tesla trailer controller unit.
 * 2024-2025 Mike Marvin (magico13)
*/

#include <WiFi.h>
#include <WebServer.h>
#include <HTTPUpdateServer.h>
#include <LittleFS.h>
#include <LEAmDNS.h>
#include <vector>

#include "lin.h"
#define VERSION "2025-11-30.6"

#define LIN_FRAME_PID 0xCF
#define TAIL_PIN 2
#define LEFT_PIN 3
#define RIGHT_PIN 4

const char* left_arrow_icon = "◄";
const char* right_arrow_icon = "►";
const char* headlight_icon = "💡";

bool output_enabled = false;
bool process_frames = true;
bool left_state = false;
bool right_state = false;
bool tail_state = false;

const char* AP_SSID     = "TCU-Access-Point";
const char* AP_PASSWORD = "123456789";

const char* OTA_USERNAME = "ota";
const char* OTA_PASSWORD = "123456789";

String wifiSSID;
String wifiPassword;
int wifiTimeout = 30;
String apSSID;
String apPassword;
String otaUsername;
String otaPassword;

bool led_state = false;
WebServer httpServer(80);
HTTPUpdateServer httpUpdater;

String latestFrameString = "";
bool lfsReady = false;
bool autoRefresh = false;

// LIN Variables
lin linStack;

// Logging Variables
struct LINFrame {
  unsigned long timestamp;
  byte sync;
  byte pid;
  byte data[8];  // Up to 8 data bytes
  byte dataLength;  // Number of actual data bytes
  byte checksum;
  byte expectedChecksum;
  bool checksumValid;
};

bool isLogging = false;
unsigned long loggingStartTime = 0;
const unsigned int LOGGING_DURATION_S = 1;
const unsigned long LOGGING_DURATION_MS = LOGGING_DURATION_S * 1000;
const unsigned int EXPECTED_FRAME_RATE_HZ = 100; // Conservative estimate
const unsigned int EXPECTED_FRAME_COUNT = (LOGGING_DURATION_MS / 1000) * EXPECTED_FRAME_RATE_HZ;
std::vector<LINFrame> frameBuffer;

// mDNS Responder
MDNSResponder mdns; // Declare mDNS responder

void flashLED(int count, int delay_ms) {
  digitalWrite(LED_BUILTIN, false);
  delay(100);
  for (int i = 0; i < count; i++) {
    digitalWrite(LED_BUILTIN, true);
    delay(delay_ms);
    digitalWrite(LED_BUILTIN, false);
    delay(delay_ms);
  }
}

String populateActiveLights() {
  String activeLights = "";
  if (left_state) {
    activeLights += left_arrow_icon; // Left arrow
  }
  if (tail_state) {
    activeLights += headlight_icon; // Light bulb
  }
  if (right_state) {
    activeLights += right_arrow_icon; // Right arrow
  }
  return activeLights;
}

void setupAccessPoint(char* ssid, char* password) {
  if (strlen(ssid) == 0) {
    ssid = (char*)AP_SSID;
  }
  if (strlen(password) == 0) {
    password = (char*)AP_PASSWORD;
  }
  Serial.print("Starting AP with SSID: ");
  Serial.println(ssid);
  WiFi.softAP(ssid, password);

  IPAddress IP = WiFi.softAPIP();
  Serial.print("AP IP address: ");
  Serial.println(IP);
}

bool setupClient(char* ssid, char* password, int timeout) {
  Serial.print("Connecting to ");
  Serial.println(ssid);
  WiFi.mode(WIFI_STA);
  //if password provided, use it, otherwise assume open network
  if (strlen(password) > 0) {
    WiFi.begin(ssid, password);
  } else {
    WiFi.begin(ssid);
  }
  Serial.println("");

  // Wait for connection, with timeout
  unsigned long timeoutMs = millis() + (timeout * 1000);
  while (WiFi.status() != WL_CONNECTED) {
    led_state = !led_state;
    digitalWrite(LED_BUILTIN, led_state);
    delay(500);
    Serial.print(".");
    if (millis() > timeoutMs) {
      Serial.print("Failed to connect to WiFi with SSID '");
      Serial.print(ssid);
      Serial.print("' pass '");
      Serial.print(password);
      Serial.println("'");
      return false;
    }
  }
  led_state = true;
  digitalWrite(LED_BUILTIN, led_state);
  Serial.println("");
  Serial.print("Connected to ");
  Serial.println(ssid);
  Serial.print("IP address: ");
  Serial.println(WiFi.localIP());
  return true;
}

float getOnboardTemperature() {
  // Get the temperature in Celsius
  float temperature_celsius = analogReadTemp();
  
  // Convert to Fahrenheit
  return temperature_celsius * 9.0 / 5.0 + 32.0;
}

void setLightState(int pin, bool state) {
  if (output_enabled) {
    digitalWrite(pin, state);
  }
}

void toggleOutputEnabled() {
  output_enabled = !output_enabled;
  process_frames = true;
  // if filesystem is ready, set the state in a file so we can read it on boot
  if (lfsReady) {
    File file = LittleFS.open("/config/output_enabled.txt", "w");
    if (file) {
      file.println(output_enabled ? "1" : "0");
      file.close();
    }
  }

  if (!output_enabled) {
    // If we're disabling the output, turn off all the lights
    digitalWrite(LEFT_PIN, false);
    digitalWrite(RIGHT_PIN, false);
    digitalWrite(TAIL_PIN, false);
  }

  Serial.print("Output enabled: ");
  Serial.println(output_enabled);
}

void processLightLINFrame(byte dataByte) {
  // First bit is left light, second bit is right light, third bit is tail light
  // This is a four pin trailer connector, so brakes and reverse do not matter, but are present in the LIN frame
  // See docs if you need to add support for those
  left_state = dataByte & 0x01;
  right_state = dataByte & 0x02;
  tail_state = dataByte & 0x04;
  setLightState(LEFT_PIN, left_state);
  setLightState(RIGHT_PIN, right_state);
  setLightState(TAIL_PIN, tail_state);
}

void runTestSequence() {
  bool original_output_enabled = output_enabled;
  output_enabled = true;
  process_frames = false;

  // Set all lights to false
  setLightState(LEFT_PIN, false);
  setLightState(RIGHT_PIN, false);
  setLightState(TAIL_PIN, false);

  setLightState(LEFT_PIN, true);
  delay(1000);
  setLightState(LEFT_PIN, false);
  setLightState(RIGHT_PIN, true);
  delay(1000);
  setLightState(RIGHT_PIN, false);
  setLightState(TAIL_PIN, true);
  delay(1000);
  setLightState(TAIL_PIN, false);
  flashLED(4, 100);

  output_enabled = original_output_enabled;
  process_frames = true;
}

#pragma region HTTP Handlers

void handleRoot() {
  process_frames = true;
  // open index.html from /web folder
  File file = LittleFS.open("/web/index.html", "r");
  if (!file) {
    httpServer.send(404, "text/plain", "File not found");
    return;
  }
  // replace placeholders in the HTML file
  String html = file.readString();
  html.replace("{active_lights}", populateActiveLights());

  html.replace("{auto_refresh}", autoRefresh ? "<meta http-equiv=\"refresh\" content=\"1\">" : "");
  html.replace("{output_status}", output_enabled ? "Active" : "Disabled");
  html.replace("{lin_frame}", latestFrameString);
  html.replace("{tcu_temp}", String(getOnboardTemperature()));
  html.replace("{logging_duration}", String(LOGGING_DURATION_S));
  html.replace("{version}", VERSION);
  httpServer.send(200, "text/html", html);
}

void handleRunTestPage() {
  // open runTest.html from /web folder
  File file = LittleFS.open("/web/runTest.html", "r");
  if (!file) {
    httpServer.send(404, "text/plain", "File not found");
    return;
  }
  httpServer.streamFile(file, "text/html");

  runTestSequence();
}

void handleSettingsPage() {
  // open settings.html from /web folder
  File file = LittleFS.open("/web/settings.html", "r");
  if (!file) {
    httpServer.send(404, "text/plain", "File not found");
    return;
  }
  String html = file.readString();
  html.replace("{current_wifi_ssid}", wifiSSID);
  html.replace("{current_wifi_password}", wifiPassword);
  html.replace("{current_wifi_timeout}", String(wifiTimeout));
  html.replace("{current_ap_ssid}", apSSID);
  html.replace("{current_ap_password}", apPassword);
  html.replace("{current_ota_username}", otaUsername);
  httpServer.send(200, "text/html", html);
}

void handleUpdateSettings() {
  // check the ota password and verify it is the same as the current one, 403 if not
  // write to serial what values we got for the ota password
  if (!httpServer.hasArg("ota_password_current") || httpServer.arg("ota_password_current") != otaPassword) {
    Serial.println("Invalid OTA password");
    httpServer.send(403, "text/plain", "Invalid OTA password");
    return;
  }
  Serial.println("Valid OTA password, updating settings...");
  
  // We do allow nulling out the wifi settings, to always use AP mode
  String newWifiSSID = "";
  if (httpServer.hasArg("wifi_ssid")) 
    newWifiSSID = httpServer.arg("wifi_ssid");
  String newWifiPassword = "";
  if (httpServer.hasArg("wifi_password")) 
    newWifiPassword = httpServer.arg("wifi_password");
  newWifiSSID.trim();
  newWifiPassword.trim();
  wifiSSID = newWifiSSID;
  wifiPassword = newWifiPassword;

  if (httpServer.hasArg("wifi_timeout")) {
    wifiTimeout = httpServer.arg("wifi_timeout").toInt();
  }

  if (httpServer.hasArg("ap_ssid") && httpServer.hasArg("ap_password")) {
    String newApSSID = httpServer.arg("ap_ssid");
    String newApPassword = httpServer.arg("ap_password");
    newApSSID.trim();
    newApPassword.trim();
    if (newApSSID.length() > 0 && newApPassword.length() > 0) {
      apSSID = newApSSID;
      apPassword = newApPassword;
    }
  }

  if (httpServer.hasArg("ota_username") && httpServer.hasArg("ota_password")) {
    String newOtaUsername = httpServer.arg("ota_username");
    String newOtaPassword = httpServer.arg("ota_password");
    newOtaUsername.trim();
    newOtaPassword.trim();
    if (newOtaUsername.length() > 0 && newOtaPassword.length() > 0) {
      otaUsername = newOtaUsername;
      otaPassword = newOtaPassword;
    }
  }

  // Save the settings to the filesystem
  if (lfsReady) {
    File wifiConfig = LittleFS.open("/config/wifi.txt", "w");
    if (wifiConfig) {
      wifiConfig.println(wifiSSID);
      wifiConfig.println(wifiPassword);
      wifiConfig.println(wifiTimeout);
      wifiConfig.close();
    }

    File apConfig = LittleFS.open("/config/ap.txt", "w");
    if (apConfig) {
      apConfig.println(apSSID);
      apConfig.println(apPassword);
      apConfig.close();
    }

    File otaConfig = LittleFS.open("/config/ota.txt", "w");
    if (otaConfig) {
      otaConfig.println(otaUsername);
      otaConfig.println(otaPassword);
      otaConfig.close();
    }
  }

  // reboot to use new settings
  httpServer.send(200, "text/plain", "Settings updated, rebooting...");
  delay(1000);
  watchdog_reboot(0, 0, 0);
}

void handleToggleOutputPage() {
  toggleOutputEnabled();
  // redirect to the main page
  httpServer.sendHeader("Location", "/",true);
  httpServer.send(302, "text/plain", "");
}

void handleToggleAutoRefresh() {
  autoRefresh = !autoRefresh;
  // redirect to the main page
  httpServer.sendHeader("Location", "/",true);
  httpServer.send(302, "text/plain", "");
}

void handleControlPage() {
  // Turn on output but turn off lin processing
  output_enabled = true;
  process_frames = false;
  if (httpServer.hasArg("id")) {
    int id = httpServer.arg("id").toInt();
    switch (id) {
      case 0: // Left Signal
        left_state = !left_state;
        break;
      case 1: // Right Signal
        right_state = !right_state;
        break;
      case 2: // Tail Lights
        tail_state = !tail_state;
        break;
      default:
        // Unrecognized id;
        break;
    }
  } else {
    // If no id is provided, turn off all lights
    left_state = false;
    right_state = false;
    tail_state = false;
  }

  setLightState(LEFT_PIN, left_state);
  setLightState(RIGHT_PIN, right_state);
  setLightState(TAIL_PIN, tail_state);

  // open control.html from /web folder
  File file = LittleFS.open("/web/control.html", "r");
  if (!file) {
    httpServer.send(404, "text/plain", "File not found");
    return;
  }
  
  String html = file.readString();
  html.replace("{active_lights}", populateActiveLights());
  httpServer.send(200, "text/html", html);
}


void handleStartLogging() {
  // Clear any existing log file and frame buffer
  if (lfsReady) {
    LittleFS.remove("/logs/lin_capture.txt");
  }
  frameBuffer.clear();
  frameBuffer.reserve(EXPECTED_FRAME_COUNT); // Pre-allocate based on expected frame rate
  
  isLogging = true;
  loggingStartTime = millis();
  process_frames = true;
  
  httpServer.send(200, "text/plain", "Logging started");
}

void handleLoggingStatus() {
  String status = "idle";
  if (isLogging) {
    unsigned long elapsed = millis() - loggingStartTime;
    if (elapsed < LOGGING_DURATION_MS) {
      status = "logging";
    } else {
      status = "complete";
    }
  }
  httpServer.send(200, "text/plain", status);
}

void handleGetLog() {
  if (!lfsReady) {
    httpServer.send(500, "text/plain", "Filesystem not ready");
    return;
  }
  
  File file = LittleFS.open("/logs/lin_capture.txt", "r");
  if (!file) {
    httpServer.send(404, "text/plain", "Log file not found");
    return;
  }
  
  httpServer.sendHeader("Content-Disposition", "attachment; filename=lin_capture.txt");
  httpServer.streamFile(file, "text/plain");
  file.close();
}

void handleLoggingConfig() {
  String json = "{\"duration\":" + String(LOGGING_DURATION_S) + "}";
  httpServer.send(200, "application/json", json);
}

void handleLoggingPage() {
  File file = LittleFS.open("/web/logging.html", "r");
  if (!file) {
    httpServer.send(404, "text/plain", "File not found");
    return;
  }
  httpServer.streamFile(file, "text/html");
  file.close();
}

#pragma endregion HTTP Handlers

void completeLogging() {
  isLogging = false;
  
  // Write buffered frames to file
  if (lfsReady && frameBuffer.size() > 0) {
    File logFile = LittleFS.open("/logs/lin_capture.txt", "w");
    if (logFile) {
      logFile.println("# LIN Frame Capture Log");
      logFile.println("# Format: timestamp_ms,sync,PID,data_bytes...,checksum,status,expected_checksum");
      logFile.println("# Status: OK = valid checksum, ERR = checksum mismatch");
      logFile.println("# expected_checksum only shown for ERR frames");
      logFile.println("# Capture duration: " + String(LOGGING_DURATION_MS) + " ms");
      logFile.println("# Total frames: " + String(frameBuffer.size()));
      logFile.println();
      
      for (const auto& frame : frameBuffer) {
        logFile.print(frame.timestamp);
        logFile.print(",0x");
        if (frame.sync < 0x10) logFile.print("0");
        logFile.print(frame.sync, HEX);
        logFile.print(",0x");
        if (frame.pid < 0x10) logFile.print("0");
        logFile.print(frame.pid, HEX);
        // Print all data bytes
        for (int i = 0; i < frame.dataLength; i++) {
          logFile.print(",0x");
          if (frame.data[i] < 0x10) logFile.print("0");
          logFile.print(frame.data[i], HEX);
        }
        logFile.print(",0x");
        if (frame.checksum < 0x10) logFile.print("0");
        logFile.print(frame.checksum, HEX);
        logFile.print(",");
        logFile.print(frame.checksumValid ? "OK" : "ERR");
        if (!frame.checksumValid) {
          logFile.print(",0x");
          if (frame.expectedChecksum < 0x10) logFile.print("0");
          logFile.print(frame.expectedChecksum, HEX);
        }
        logFile.print("\r\n");  // Use explicit CR+LF for better compatibility
        logFile.flush();  // Force flush after each frame
      }
      
      logFile.close();
      Serial.println("Log file written with " + String(frameBuffer.size()) + " frames");
    }
  }
}


void setup(void) {
  // set control pins as an output and set them to LOW
  pinMode(LEFT_PIN, OUTPUT);
  pinMode(RIGHT_PIN, OUTPUT);
  pinMode(TAIL_PIN, OUTPUT);
  digitalWrite(LEFT_PIN, false);
  digitalWrite(RIGHT_PIN, false);
  digitalWrite(TAIL_PIN, false);

  pinMode(LED_BUILTIN, OUTPUT); 
  led_state = true;
  digitalWrite(LED_BUILTIN, led_state);
  Serial.begin(115200);
  Serial.println("Booting");

  // Setup LittleFS
  lfsReady = LittleFS.begin();
  if (!lfsReady) {
    Serial.println("An Error has occurred while mounting LittleFS");
  }

  // Load configuration
  if (lfsReady) {
    File wifiConfig = LittleFS.open("/config/wifi.txt", "r");
    if (wifiConfig && wifiConfig.size() > 0) {
      wifiSSID = wifiConfig.readStringUntil('\n');
      wifiSSID.trim();
      wifiPassword = wifiConfig.readStringUntil('\n');
      wifiPassword.trim();
      wifiTimeout = wifiConfig.parseInt();
      wifiConfig.close();
    }

    File apConfig = LittleFS.open("/config/ap.txt", "r");
    if (apConfig && apConfig.size() > 0) {
      apSSID = apConfig.readStringUntil('\n');
      apSSID.trim();
      apPassword = apConfig.readStringUntil('\n');
      apPassword.trim();
      apConfig.close();
    }

    File otaConfig = LittleFS.open("/config/ota.txt", "r");
    if (otaConfig && otaConfig.size() > 0) {
      otaUsername = otaConfig.readStringUntil('\n');
      otaUsername.trim();
      otaPassword = otaConfig.readStringUntil('\n');
      otaPassword.trim();
      otaConfig.close();
    }

    // If we were active before, we should stay active until disabled
    // We might reboot just because the doors are all closed in park
    // So we should remember the state
    File outputConfig = LittleFS.open("/config/output_enabled.txt", "r");
    if (outputConfig && outputConfig.size() > 0) {
      output_enabled = outputConfig.parseInt();
      outputConfig.close();
    }
  }

  // Setup WiFi
  bool wifiConnected = false;
  if (wifiSSID.length() > 0 && wifiPassword.length() > 0) {
    char wifiSSIDArray[32];
    char wifiPasswordArray[32];
    wifiSSID.toCharArray(wifiSSIDArray, 32);
    wifiPassword.toCharArray(wifiPasswordArray, 32);
    wifiConnected = setupClient(wifiSSIDArray, wifiPasswordArray, wifiTimeout);
  }

  if (!wifiConnected) {
    // Fallback to AP mode if WiFi fails/has not been configured
    char apSSIDArray[32];
    char apPasswordArray[32];
    apSSID.toCharArray(apSSIDArray, 32);
    apPassword.toCharArray(apPasswordArray, 32);
    setupAccessPoint(apSSIDArray, apPasswordArray);
  }

  // Set hostname for the server
  const char* hostname = "trailercontroller";
  WiFi.setHostname(hostname);

  // Start mDNS service using LEAmDNS
  if (mdns.begin(hostname)) {
    Serial.println("mDNS responder started. Hostname: " + String(hostname) + ".local");
    mdns.addService("http", "tcp", 80); // Add HTTP service on port 80
  } else {
    Serial.println("Error setting up mDNS responder");
  }

  // Setup LIN
  linStack.setupSerial();

  // Setup OTA
  if (otaUsername.length() == 0) {
    otaUsername = OTA_USERNAME;
  }
  if (otaPassword.length() == 0) {
    otaPassword = OTA_PASSWORD;
  }
  httpUpdater.setup(&httpServer, otaUsername, otaPassword);

  // Setup HTTP server
  httpServer.on("/", handleRoot);
  httpServer.on("/runTest", handleRunTestPage);
  httpServer.on("/settings", handleSettingsPage);
  httpServer.on("/updateSettings", handleUpdateSettings);
  httpServer.on("/toggleOutput", handleToggleOutputPage);
  httpServer.on("/autoRefresh", handleToggleAutoRefresh);
  httpServer.on("/control", handleControlPage);
  httpServer.on("/logging", handleLoggingPage);
  httpServer.on("/loggingConfig", handleLoggingConfig);
  httpServer.on("/startLogging", handleStartLogging);
  httpServer.on("/loggingStatus", handleLoggingStatus);
  httpServer.on("/getLog", handleGetLog);
  httpServer.onNotFound([]() {
    httpServer.send(404, "text/plain", "File not found");
  });
  httpServer.begin();

  Serial.println("HTTP server started");
  led_state = false;
  digitalWrite(LED_BUILTIN, led_state);
}

void loop(void) {
  httpServer.handleClient();

  // Handle mDNS queries
  mdns.update();

  // Handle logging completion
  if (isLogging && (millis() - loggingStartTime >= LOGGING_DURATION_MS)) {
    completeLogging();
  }

  // Handle LIN frames
  if (process_frames) {
    // Process all available frames - keep calling updateFrame until no more frames available
    short bytesRead;
    while ((bytesRead = linStack.updateFrame(isLogging ? 0 : LIN_FRAME_PID)) > 0) {
      // Check if the checksum is valid
      byte calculatedChecksum = linStack.calculateChecksum(linStack.dataBuffer, bytesRead - 1);
      byte receivedChecksum = linStack.dataBuffer[bytesRead - 1];
      bool checksumValid = (calculatedChecksum == receivedChecksum);
      
      // If logging, just capture the frame data without processing for display
      if (isLogging) {
        if (millis() - loggingStartTime >= LOGGING_DURATION_MS) {
          break;
        }

        LINFrame frame;
        frame.timestamp = millis() - loggingStartTime;
        frame.sync = linStack.dataBuffer[0];
        frame.pid = linStack.dataBuffer[1];
        // Store data bytes (everything between PID and checksum)
        frame.dataLength = bytesRead - 3;  // Total - sync - PID - checksum
        if (frame.dataLength > 8) {
          frame.dataLength = 8; // Cap at 8 bytes
        }
        for (int i = 0; i < frame.dataLength && i < 8; i++) {
          frame.data[i] = linStack.dataBuffer[2 + i];
        }
        frame.checksum = receivedChecksum;
        frame.expectedChecksum = calculatedChecksum;
        frame.checksumValid = checksumValid;
        frameBuffer.push_back(frame);
      } else {
        // Only build the display string when not logging
        latestFrameString = "";
        for (int i = 0; i < bytesRead; i++) {
          latestFrameString += "0x" + String(linStack.dataBuffer[i], HEX) + " ";
        }
        
        if (checksumValid) {
          latestFrameString += "OK";
          // Only process light frame if it's the expected PID and checksum is valid
          if (linStack.dataBuffer[1] == LIN_FRAME_PID) {
            processLightLINFrame(linStack.dataBuffer[2]);
          }
        } else {
          latestFrameString += "ERR 0x" + String(calculatedChecksum, HEX);
        }
        
        Serial.print(latestFrameString);
      }
    }
  }
}

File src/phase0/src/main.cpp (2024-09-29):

/*
 * Provides a base for an ESP32 LIN sniffer with OTA updates.
 * Based on the ElegantOTA example for OTA updates.
*/

#include <WiFi.h>
#include <AsyncTCP.h>
#include <ESPAsyncWebServer.h>
#include <ElegantOTA.h>
#include <HardwareSerial.h>

#include "lin.h"
#include "wifi_creds.h"

const char* ESP32_AP_SSID     = "ESP32-Access-Point";
const char* ESP32_AP_PASSWORD = "123456789";

bool state = false;
AsyncWebServer server(80);

unsigned long ota_progress_millis = 0;

// LIN Variables
// const byte ident = 1; // Identification Byte
// const byte data_size=8; // length of byte array
// const byte frame_size = data_size+3; // length of LIN frame
// byte data[frame_size]; // byte array for received data

// lin_stack_esp32 LIN1(2,ident); // 2 - channel (GPIO 16 & 17), ident - Identification Byte

lin linStack;
byte data[lin::MAX_BYTES];

void flashLED(int count, int delay_ms) {
  digitalWrite(LED_BUILTIN, false);
  delay(100);
  for (int i = 0; i < count; i++) {
    digitalWrite(LED_BUILTIN, true);
    delay(delay_ms);
    digitalWrite(LED_BUILTIN, false);
    delay(delay_ms);
  }
}

void onOTAStart() {
  // Log when OTA has started
  Serial.println("OTA update started!");
  flashLED(3, 100);
}

void onOTAProgress(size_t current, size_t final) {
  // Log every 1 second
  if (millis() - ota_progress_millis > 1000) {
    ota_progress_millis = millis();
    Serial.printf("OTA Progress Current: %u bytes, Final: %u bytes\n", current, final);
    state = !state;
    digitalWrite(LED_BUILTIN, state);
  }
}

void onOTAEnd(bool success) {
  // Log when OTA has finished
  if (success) {
    Serial.println("OTA update finished successfully!");
    flashLED(3, 250);
  } else {
    Serial.println("There was an error during OTA update!");
    flashLED(10, 250);
  }
}

void setupAccessPoint() {
  Serial.print("Setting AP...");
  WiFi.softAP(ESP32_AP_SSID, ESP32_AP_PASSWORD);

  IPAddress IP = WiFi.softAPIP();
  Serial.print("AP IP address: ");
  Serial.println(IP);
}

void setupClient() {
  WiFi.mode(WIFI_STA);
  WiFi.begin(WIFI_SSID, WIFI_PASSWORD);
  Serial.println("");

  // Wait for connection
  while (WiFi.status() != WL_CONNECTED) {
    state = !state;
    digitalWrite(LED_BUILTIN, state);
    delay(500);
    Serial.print(".");
  }
  state = true;
  digitalWrite(LED_BUILTIN, state);
  Serial.println("");
  Serial.print("Connected to ");
  Serial.println(WIFI_SSID);
  Serial.print("IP address: ");
  Serial.println(WiFi.localIP());
}

void setup(void) {
  pinMode(LED_BUILTIN, OUTPUT); 
  state = true;
  digitalWrite(LED_BUILTIN, state);
  Serial.begin(115200);
  Serial.println("Booting");

  // Setup WiFi
  // If WiFi credentials are not provided, start Access Point
  if (strlen(WIFI_SSID) > 0 && strlen(WIFI_PASSWORD) > 0) {
    setupClient();
  } else {
    setupAccessPoint();
  }

  // Setup LIN
  //LIN1.setSerial();
  linStack.setupSerial(16);

  server.on("/", HTTP_GET, [](AsyncWebServerRequest *request) {
    request->send(200, "text/plain", "Hi! This is ElegantOTA AsyncDemo.");
  });

  ElegantOTA.begin(&server);    // Start ElegantOTA
  // ElegantOTA callbacks
  ElegantOTA.onStart(onOTAStart);
  ElegantOTA.onProgress(onOTAProgress);
  ElegantOTA.onEnd(onOTAEnd);

  server.begin();
  Serial.println("HTTP server started");
  state = false;
  digitalWrite(LED_BUILTIN, state);
}

void loop(void) {
  ElegantOTA.loop();

  int bytesRead = linStack.readFrame(data, 0xCF);
  if (bytesRead > 2) {
    byte calculatedChecksum = linStack.calculateChecksum(data, bytesRead - 1);
    for (int i = 0; i < bytesRead; i++) {
      Serial.print(data[i], HEX);
      Serial.print(" ");
    }
    byte receivedChecksum = data[bytesRead - 1];
    if (calculatedChecksum == receivedChecksum) {
      Serial.print("OK");
    } else {
      Serial.print("ERR ");
      Serial.print(calculatedChecksum, HEX);
    }
    Serial.println();
  }

  // TODO: Use webserver to view data instead of serial monitor
}

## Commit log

2024-09-24 Populate readme and info about connector and LIN. Add inital OTA demo source to Phase0 files.
2024-09-26 Add LIN bus information and example trace for inductive charger LIN bus
2024-09-29 Add info about lin frames and signal frame
2024-09-29 Add more info about lights and inductive charger LIN bus
2024-09-29 Reformat headers for wireless chargers
2024-09-29 Calculate checksum and invert bits
    [lin.cpp]
2024-10-01 Add circuit diagram
2024-10-03 Add start of phase 1 with Pico W
2024-10-03 Use UART0
2024-10-05 WIP controlling the MOSFETs
2024-10-05 Add WIP Phase1 PCB and schematic with LibrePCB
2024-10-06 Still working on PCB
2024-10-07 More PCB work
    [phase1_COPPER-BOTTOM.gbr, phase1_COPPER-TOP.gbr, phase1_DRILLS-NPTH.drl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]
2024-10-07 Add note about PCB
2024-10-10 Refactor LIN frame processing and add control for trailer lights
2024-10-13 Refactor pin assignments for trailer lights
2024-10-22 Add TCU temperature display on web page
2024-10-26 Toggle active power output. Autorefresh. Use icons instead of ON/OFF.
2024-11-05 Add details about the successful prototype build.
2024-11-05 Add enclosure model pic, add pic to readme. Correction about M3 bolt size.
2024-11-05 Add potential improvements to bottom of prototype doc.
2025-04-26 Clean up the old LIN code by avoiding double loops over the bytes
    [main.cpp]
2025-04-26 Fix bug with updateFrame always returning zero. Refactor logging a bit in new method.
    [lin.cpp, main.cpp]
2025-04-26 Remove commented-out LIN frame reading code from loop function
2025-11-30 First pass at capturing LIN logs on-device. Needs to be tested in hardware still.
2025-11-30 Attempt to fix logging issues and log all frame data
    [main.cpp]
2025-11-30 Attempt to make LIN processing more robust, but we really need to swap to something with better timing instead.
    [lin.cpp, main.cpp]
2026-04-06 Docs updates showing updated prototype enclosure.
2026-04-06 Official is also a 4-pin and adding part number for the wire from ECU to adapter.
